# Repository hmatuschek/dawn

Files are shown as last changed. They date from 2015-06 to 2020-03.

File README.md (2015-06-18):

# Bluetooth controlled dawn simulator

This is a simple Bluetooth controlled bedside light which can act as a dawn simulator.

**Disclaimer**: The hardware schematics provided here deal with relatively high currents 
(depending on the LED used, >1A) which may even cause fire. If you rebuild the hardware,
you do that on our own risk! I am not responsible for any damage caused by the circuits 
or the software provided here. In general, do not rebuild the hardware if you do not 
understand the circuit completely!

## Hardware

The hardware ([schematics](https://github.com/hmatuschek/dawn/blob/master/doc/lampe_brd.pdf) 
can be found in the hardware/ directory) consists of a high-power LED, a current regulator
(BUZ11 + 2x BC547),  an ATMega168 MCU, a real-time clock (DS1307) with back-up battery
and a RS232 Bluetooth interface module (JY-MCU).

The [circuit](https://github.com/hmatuschek/dawn/blob/master/doc/lampe_brd.pdf) can be 
adopted easily to different LEDs by changing the value of R25 and/or R30 such that 
R25||R30 = 0.6/Imax, where Imax is the maximum current through the LED. Please be aware 
that the MOSFET Q4 as well as the LED may need some cooling.

The brightness of the LED will be controlled by the PWM output (pin 15) of the ATMega.

The firmware for the ATMega168 can be found in the firmware/ directory.

## Software

The software can be found in the src/ directory and provides a simple GUI using QT5 to configure and
control the dawn simulator. 

The dawn simulator is interfaced via Bluetooth, hence you must first connect to the device using the 
OS Bluetooth configuration. This will create a new serial port (RS232) which needs to be selected 
within the GUI application. 

## Communication protocol

The communication protocol is a trivial binary one. Every command/request is transmitted in terms of 
messages. The basic message structure is

    +--------+-- ... --+-- ... --+
    |  CMD   | PAYLOAD |   MAC   |
    +--------+---... --+-- ... --+

Each command message consists of a 8-bit command field, an optional Payload (variable size)
and a message authentication code (64 bit).

The RS232 Bluetooth module has only a 4-digit PIN for the access control. Hence some
additional measures are needed. Every message send to the device is therefore authenticated
using a simple MAC. The MAC is computed over the CMD and PAYLOAD fields of the message 
using the SIPHASH(2,4) function with a shared secret. This does not provide a very high 
level of security but may be considered sufficient for a bedside light.

Please note that the device will not send any response on an error. I.e. if an invalid command is received 
or if the MAC is invalid.

### (H)MAC algorithm

The signature (64bit) is simply the SipHash-2-4 of the message body with a shared 128bit secret.

  MAC = siphash24(MESSAGE, SECRET)

Please note that there is no IV that changes with every command. Hence the protocol is in principle 
vulnerable to replay attacks. Although the Bluetooth authentication is secured using a trivial 
4-digit PIN, the actual communication is encrypted with a relatively strong algorithm and key. 
Unless an attacker is able to capture the pairing, the communication should be relatively robust 
against trivial replay attacks. 

### GET_VALUE command (0x01)

Returns the current luminescence value of the lamp. This command has no payload.

The response contains the current value as a uint16_t as the payload.

### SET_VALUE command (0x02)

Sets the current luminescence value of the lamp.

The command payload contains the value as a uint16_t.

On success, a single byte (0x00) is returned.

### GET_TIME command (0x03)

Returns the current date and time of the RTC.

The command has no payload.

The response payload has the following structure

YEAR:MONTH:DAY:DAYOFWEEK:HOUR:MINTUE:SECOND

Where YEAR is transmitted as a uint16_t and MONTH, DAY, DAYOFWEEK, HOUR, MINUTE and SECOND as
uint8_t.

### SET_TIME command (0x04)

Set the current date and time of the RTC.

The command payload has the following structure

YEAR:MONTH:DAY:DAYOFWEEK:HOUR:MINTUE:SECOND

Where YEAR is transmitted as a uint16_t and MONTH, DAY, DAYOFWEEK, HOUR, MINUTE and SECOND as
uint8_t.

On success, a single byte (0x00) is returned.

### GET_ALARM command (0x05)

Returns the settings for the i-th alarm, where i in [0,6]

The payload contains the index of the alarm as a uint8_t.

The response Payload has the following format

DOW_FLAGS:HOUR:MINUTE

The first bit (MSB) is reserved (0), followed by 7 bits encoding the day of the week at which 
the alarm is enabled. 

0b0000001 - Sunday
0b0000010 - Monday
0b0000100 - Tuesday
0b0001000 - Wednesday
0b0010000 - Thursday
0b0100000 - Friday
0b1000000 - Saturday

Hence a value of 0x7f will enable the alarm on every day and a value of 0x00 will effectively disable
the alarm.

HOUR and MINUTE are encoded as uint8_t.

### SET_ALARM command (0x06)

Sets the i-th alarm settings, where i in [0,6].

The command payload has the following format:

IDX:DOW_FLAGS:HOUR:MINUTE

Where IDX is encodes the alarm index as uint8_t. The 7 least significant bits of DOW_FLAGS encode 
the day of the week at which the alarm is enabled.

0b0000001 - Sunday
0b0000010 - Monday
0b0000100 - Tuesday
0b0001000 - Wednesday
0b0010000 - Thursday
0b0100000 - Friday
0b1000000 - Saturday

HOUR and MINUTE are encoded as uint8_t.

### GET_TEMP command (0x07)

Returns the core and ambient temperature in K.

The response has the following format

CORE_TEMP:AMB_TEMP

where both variables are 16bit integer values (MSB first). Some MCUs do not
provide a core temperature sensor. In this case 0xffff is returned.

## License

dawn - A dawn-simulating bedside light.

Copyright (C) 2015  Hannes Matuschek

This program and harware is "free software"; you can redistribute it 
and/or modify it under the terms of the GNU General Public License
as published by the Free Software Foundation; either version 2 of 
the License, or (at your option) any later version.

This program and hardware is distributed in the hope that it will be useful,
but WITHOUT ANY WARRANTY; without even the implied warranty of
MERCHANTABILITY or FITNESS FOR A PARTICULAR PURPOSE.  See the
GNU General Public License for more details.

You should have received a copy of the GNU General Public License along
with this program; if not, write to the Free Software Foundation, Inc.,
51 Franklin Street, Fifth Floor, Boston, MA 02110-1301 USA.

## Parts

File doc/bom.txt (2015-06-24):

Qty Value           Device             Package         Parts    Description                          
1   10              R-EU_0204/7        0204/7          R24      RESISTOR
1   560             R-EU_0207/17       0207/17         R26      RESISTOR, European symbol            
2   1k              R-EU_0204/2V       0204V           R1, R28  RESISTOR
1   4.7k            R-EU_0207/10       0207/10         R27      RESISTOR, European symbol            
4   10k             R-EU_0204/2V       0204V           R13, R29, R12, R11 RESISTOR
1   1W              R-EU_0411/12       0411/12         R25      RESISTOR
1   10k             B57164             B57164          R2       SIEMENS NTC                          

2   22pF            C-EU025-025X050    C025-025X050    C7,C6    CAPACITOR
2   100nF           C-EU025-025X050    C025-025X050    C8, C9   CAPACITOR, European symbol           
1   100pF           C-EU025-025X050    C025-025X050    C10      CAPACITOR, European symbol           
1   100uF/35V       CPOL-EUE5-6        E5-6            C1       POLARIZED CAPACITOR

1   100uH           L-EU6000-XXX-RC    6000-XXXX-RC    L1       INDUCTOR, European symbol            

1   32.768kHz       CRYSTALTC26V       TC26V           Q3       CRYSTAL                              
1   16Mhz           CRYSTALHC18U-V     HC18U-V         Q2       CRYSTAL                              

1   ATMEGA328-20P   ATMEGA328-20P      DIL28-3         IC1      MICROCONTROLLER                      
1   JY-MCU          JY-MCU             JY-MCU          U$1      BLUETOOTH MODULE                                     

1   SB140           ZENER-DIODEDO35Z10 DO35Z10         D1       Z-Diode                              
2   BC547B          -NPN-TO92-EBC      TO92-EBC        T3, T4   NPN Transistror                      
1   BUZ11BV         BUZ11BV            TO220BV         Q4       N-CHANNEL MOS FET                    
1   DS1307          DS1307             DIL08           IC3      DS1307                               

2   MKDSN1,5/2-5,08 MKDSN1,5/2-5,08    MKDSN1,5/2-5,08 X1, X2   MKDSN 1,5/ 2-5,08 Printklemme        
1   PF750           PF750              PF752           KK1      HEATSINK                             
1   SL-340/P        SL-340/P           BEL/P           G1       LI BATTERY Sonnenschein

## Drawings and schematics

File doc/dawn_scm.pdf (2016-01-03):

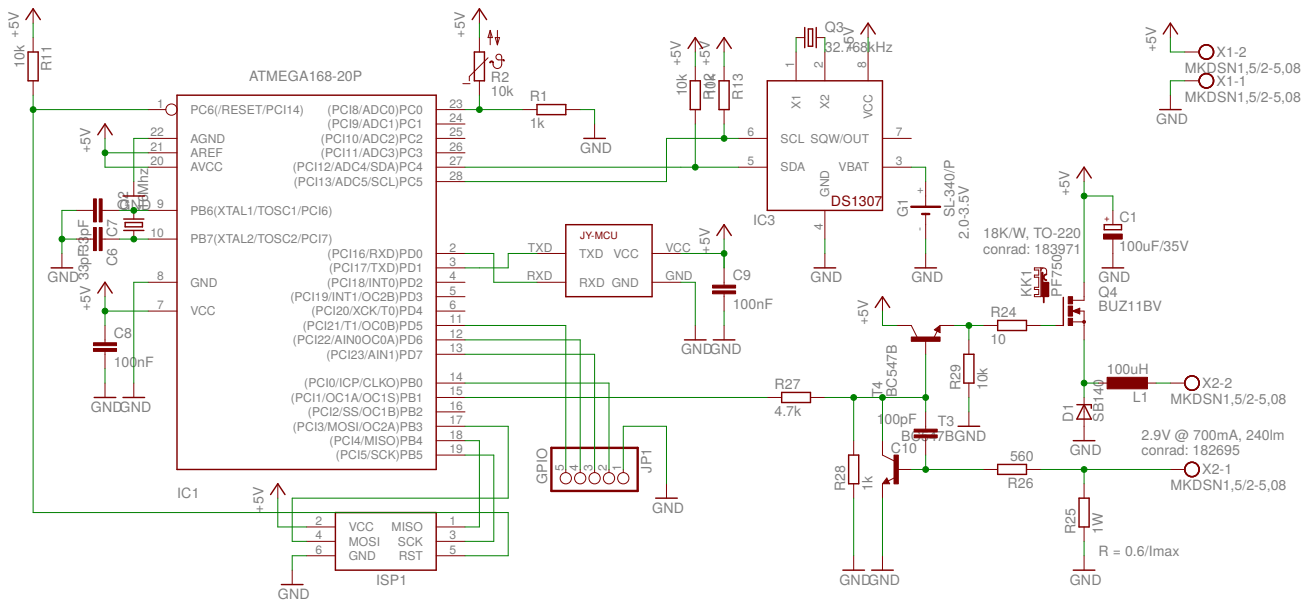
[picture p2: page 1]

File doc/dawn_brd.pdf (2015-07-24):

68.58

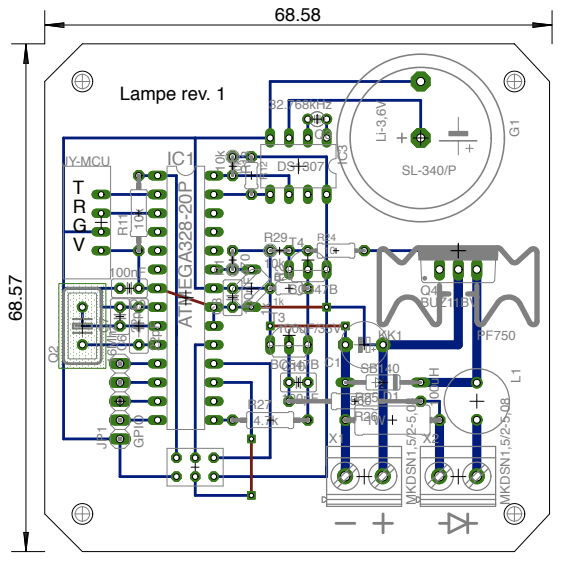
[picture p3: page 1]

JY-MCU
T R V

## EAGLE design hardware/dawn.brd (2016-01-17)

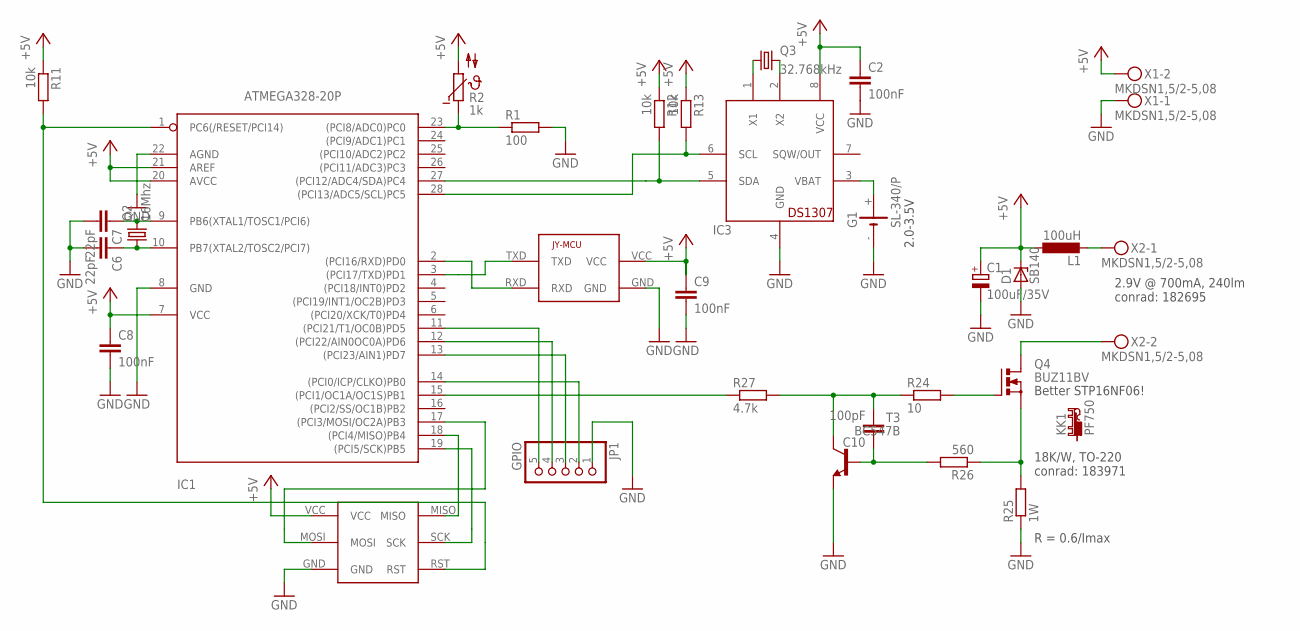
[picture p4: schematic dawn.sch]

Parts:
C1: 100uF/35V; E5-6
C2, C8, C9: 100nF; C025-025X050
C6: 22pF; C050-025X075
C7: 22pF; C025-025X050
C10: 100pF; C025-025X050
D1: SB140; DO35Z10
G1: SL-340/P; BEL/P
IC1: ATMEGA328-20P; DIL28-3
IC3: DS1307; DIL08
JP1: GPIO; 1X05
KK1: PF750; PF752
L1: 100uH; 6000-XXXX-RC
Q2: 16Mhz; HC18U-V
Q3: 32.768kHz; TC26V
Q4: BUZ11BV; TO220BV
R1: 100; 0204V
R2: 1k; B57164
R11: 10k; 0207/10
R12: 10k; 0204/5
R13: 10k; 0204V
R24: 10; 0204/7
R25: 1W; 0411/12
R26: 560; 0207/17
R27: 4.7k; 0207/10
T3: BC547B; TO92-EBC
U$1: JY-MCU
U$2: AVR-ISP
X1, X2: MKDSN1,5/2-5,08

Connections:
+5V: C1.+, C2.1, C8.1, C9.1, D1.C, IC1.7 (VCC), IC1.20 (AVCC), IC1.21 (AREF), IC3.8 (VCC), L1.1, R2.2, R11.1, R12.1, R13.1, U$1.VCC, U$2.VCC, X1.2
GND: C1.-, C2.2, C6.2, C7.2, C8.2, C9.2, D1.A, G1.-, IC1.8 (GND), IC1.22 (AGND), IC3.4 (GND), JP1.1, R1.2, R25.1, T3.E, U$1.GND, U$2.GND, X1.1
unnamed: IC1.15 ((PCI1/OC1A/OC1S)PB1), R27.1
unnamed: IC1.18 ((PCI4/MISO)PB4), U$2.MISO
unnamed: IC1.19 ((PCI5/SCK)PB5), U$2.SCK
unnamed: IC1.1 (PC6(/RESET/PCI14)), R11.2, U$2.RST
unnamed: IC1.17 ((PCI3/MOSI/OC2A)PB3), U$2.MOSI
unnamed: IC1.12 ((PCI22/AIN0OC0A)PD6), JP1.4
unnamed: IC1.11 ((PCI21/T1/OC0B)PD5), JP1.5
unnamed: IC1.13 ((PCI23/AIN1)PD7), JP1.3
unnamed: IC1.14 ((PCI0/ICP/CLKO)PB0), JP1.2
unnamed: IC1.23 ((PCI8/ADC0)PC0), R1.1, R2.1
unnamed: L1.2, X2.1
unnamed: C7.1, IC1.9 (PB6(XTAL1/TOSC1/PCI6)), Q2.2
unnamed: IC3.2 (X2), Q3.2
unnamed: IC3.1 (X1), Q3.1
unnamed: Q4.D, X2.2
unnamed: C6.1, IC1.10 (PB7(XTAL2/TOSC2/PCI7)), Q2.1
unnamed: IC1.28 ((PCI13/ADC5/SCL)PC5), IC3.6 (SCL), R13.2
unnamed: IC1.27 ((PCI12/ADC4/SDA)PC4), IC3.5 (SDA), R12.2
unnamed: G1.+, IC3.3 (VBAT)
unnamed: IC1.3 ((PCI17/TXD)PD1), U$1.TXD
unnamed: IC1.2 ((PCI16/RXD)PD0), U$1.RXD
unnamed: Q4.G, R24.2
unnamed: Q4.S, R25.2, R26.1
unnamed: C10.1, R26.2, T3.B
unnamed: C10.2, R24.1, R27.2, T3.C

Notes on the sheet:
2.9V @ 700mA, 240lm conrad: 182695
18K/W, TO-220 conrad: 183971
2.0-3.5V
R = 0.6/Imax
Better STP16NF06!

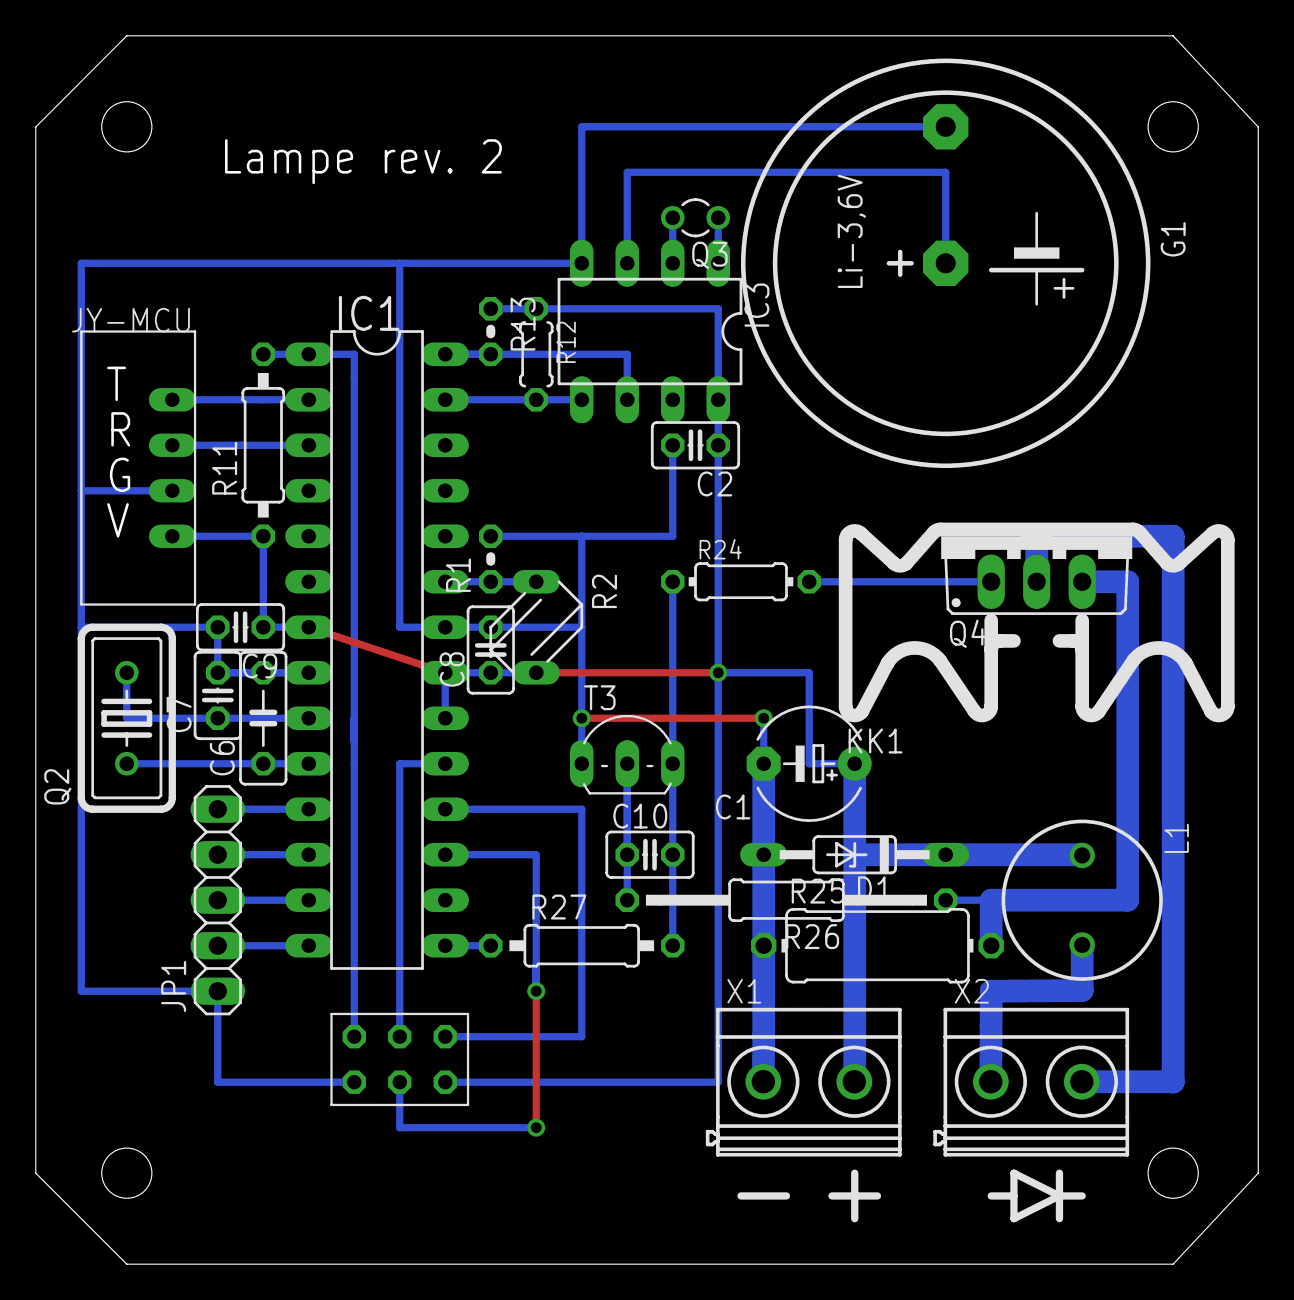
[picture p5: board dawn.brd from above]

Board: 2 copper layers, 68.2 x 68.6 mm, 31 parts (0 on the bottom side), 27 nets.

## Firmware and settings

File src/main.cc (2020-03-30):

#include <QApplication>
#include <QSerialPort>
#include <QMessageBox>
#include <QDateTime>
#include <QTranslator>
#include <QSettings>

#include "portdialog.hh"
#include "dawn.hh"
#include "mainwindow.hh"
#include "logger.hh"

#include <iostream>
#include <time.h>


int main(int argc, char *argv[])
{
  QApplication app(argc, argv);
  app.setApplicationName("dawn");
  app.setOrganizationDomain("hmatuschek.github.io");

  QTranslator translator;
  translator.load("://i18n/dawn.qm");
  app.installTranslator(&translator);

  QSettings settings("hmatuschek.github.io", "dawn");

  Logger::get().addHandler(new StreamLogHandler(LOG_DEBUG, std::cerr));

  Dawn *dawn = nullptr;
  QString name, systemLocation;
  QByteArray secret;

  // Let the user select an interfact to the device:
  while (true) {
    DeviceDialog dialog(settings);
    if (QDialog::Accepted != dialog.exec()) { return 0; }

    name = dialog.name();
    systemLocation = dialog.systemLocation();
    secret = dialog.secret();
    if (16 != secret.size()) { secret.resize(16); }

    QSerialPort *port = new QSerialPort(systemLocation);

    // Open port
    port->open(QIODevice::ReadWrite);
    if (! port->isOpen()) {
      LogMessage msg(LOG_ERROR);
      msg << "IO Error: Can not open device " << systemLocation.toStdString();
      Logger::get().log(msg);
      goto error;
    }
    if (! port->setBaudRate(QSerialPort::Baud38400)) {
      LogMessage msg(LOG_ERROR);
      msg << "IO: Can not set baudrate.";
      Logger::get().log(msg);
      goto error;
    }
    if (! port->setDataBits(QSerialPort::Data8)) {
      LogMessage msg(LOG_ERROR);
      msg << "IO: Can not set data bits.";
      Logger::get().log(msg);
      goto error;
    }
    if (! port->setParity(QSerialPort::NoParity)) {
      LogMessage msg(LOG_ERROR);
      msg << "IO: Can not set parity.";
      Logger::get().log(msg);
      goto error;
    }
    if (! port->setStopBits(QSerialPort::OneStop)) {
      LogMessage msg(LOG_ERROR);
      msg << "IO: Can not set stop bits.";
      Logger::get().log(msg);
      goto error;
    }
    if (! port->setFlowControl(QSerialPort::HardwareControl)) {
      LogMessage msg(LOG_ERROR);
      msg << "IO: Can not set stop bits.";
      Logger::get().log(msg);
      goto error;
    }
    if (! port->setDataTerminalReady(true)) {
      LogMessage msg(LOG_ERROR);
      msg << "IO: Can not set DTR.";
      Logger::get().log(msg);
      goto error;
    }

    dawn = new Dawn(port, (const uint8_t *)secret.constData());

    break;

error:
      QMessageBox::critical(
            0, QObject::tr("Can not access device."),
            QObject::tr("Can not access device at interface %1 (%2).").arg(
              name, systemLocation));
      if (dawn)
        delete dawn;
      else
        delete port;
      dawn = nullptr;
  }

  // Create main window
  MainWindow window(*dawn);
  window.show();

  // go...
  app.exec();

  return 0;
}

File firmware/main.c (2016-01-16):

#include <avr/io.h>
#include <avr/interrupt.h>
#include "communication.h"
#include "clock.h"
#include "temp.h"
#include "pwm.h"
#include "uart.h"

#include "i2c.h"
#include "ds1307.h"

int main(void)
{
  // Initialize UART interface
  comm_init();
  // Init all
  clock_init();
  // Init ADC
  temp_init();

  // Enable interrupts
  sei();

  // Wait for commands
  Command cmd;
  while (1) {
    if (! comm_wait(&cmd)) {
      comm_send_err();
      continue;
    }

    // Dispatch by command
    switch (cmd.command)
    {
      case GET_VALUE:
        comm_send_value(clock_get_value());
        break;

      case SET_VALUE:
        clock_set_value(cmd.payload.value);
        comm_send_ok();
        break;

      case GET_TIME:
        clock_get_datetime(&cmd.payload.datetime);
        comm_send_time(&cmd.payload.datetime);
        break;

      case SET_TIME:
        if (clock_set_datetime(&cmd.payload.datetime) ) {
          comm_send_ok();
        } else {
          comm_send_err();
        }
        break;

      case GET_ALARM:
        clock_get_alarm(cmd.payload.alarmIdx, &cmd.payload.alarm.alarm);
        comm_send_alarm(&cmd.payload.alarm.alarm);
        break;

      case SET_ALARM:
        if(clock_set_alarm(cmd.payload.alarm.alarmIdx, &cmd.payload.alarm.alarm)) {
          comm_send_ok();
        } else {
          comm_send_err();
        }
        break;

      case GET_TEMP:
        comm_send_temp(temp_get_core(), temp_get_external());
        break;

      case GET_NALARM:
        comm_send_nalarm(CLOCK_N_ALARM);
        break;

      case GET_NONCE:
        comm_send_nonce();
        break;

      default:
        comm_send_err();
        break;
    }
  }

  return 0;
}

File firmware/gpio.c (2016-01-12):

#include "gpio.h"
#include <avr/io.h>

// PIN0 -> PB0
// PIN1 -> PD7
// PIN2 -> PD6
// PIN3 -> PD5

#define KEY_HOLD_DUR  100

typedef struct {
  KeyState last_state;
  KeyState state;
  uint16_t tick_count;
} KeyContext;

static KeyContext keys[3] = {
  {KEY_NONE, KEY_NONE, 0},
  {KEY_NONE, KEY_NONE, 0},
  {KEY_NONE, KEY_NONE, 0}
};

void
key_init() {
  // PD7, PD6, PD5 are inputs
  DDRD  &= ~((1 << DDD7) | (1 << DDD6) | (1 << DDD5));
  // Enables pull-ups
  PORTD |= ((1 << DDD7) | (1 << DDD6) | (1 << DDD5));
  // Init keys
  keys[0].last_state = keys[0].state = KEY_NONE;  keys[0].tick_count = 0;
  keys[1].last_state = keys[1].state = KEY_NONE;  keys[1].tick_count = 0;
  keys[2].last_state = keys[2].state = KEY_NONE;  keys[2].tick_count = 0;
}


void key_update(uint8_t key) {
  // Get current output values:
  uint8_t k   = 1;
  switch (key) {
  case 0: k = (PIND & (1<<DDD7)); break;
  case 1: k = (PIND & (1<<DDD6)); break;
  case 2: k = (PIND & (1<<DDD5)); break;
  }
  if (0 == k) {
    switch (keys[key].last_state) {
    case KEY_NONE:
      keys[key].last_state = KEY_CLICK;
      keys[key].tick_count = 0;
      break;
    case KEY_CLICK:
      if (keys[key].tick_count == 5) {
        keys[key].last_state = KEY_HOLD;
        keys[key].state      = KEY_HOLD;
      } else {
        keys[key].tick_count++;
      }
      break;
    case KEY_HOLD:
      break;
    }
  } else {
    switch (keys[key].last_state) {
    case KEY_NONE:
      keys[key].state = KEY_NONE;
      break;
    case KEY_CLICK:
      keys[key].last_state = KEY_NONE;
      keys[key].state      = KEY_CLICK;
      break;
    case KEY_HOLD:
      keys[key].last_state = KEY_NONE;
      keys[key].state      = KEY_NONE;
      break;
    }
    keys[key].tick_count = 0;
  }
}


KeyState key(uint8_t key) {
  return keys[key].state;
}

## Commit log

2014-11-22 Initial import.
    [lampe.brd, lampe.sch]
2014-11-23 Fixed schematic & board.
    [dawn.brd, dawn.sch]
2015-06-17 Fixed current reg.
    [lampe.brd, lampe.sch]
2015-06-17 Updated circuit and board PDFs.
    [lampe.brd, lampe.sch]
2015-06-18 Fixed build scripts for compilation under linux.
    [clock.c]
2015-06-18 Updated schematics and firmware for ATMEGA328P.
    [dawn.brd, dawn.sch]
2015-07-27 Fixed touch sensor code.
    [gpio.c]
2015-07-27 Fixed stupid error in keygen.
    [communication.c]
2016-01-03 Fixed minors.
    [dawn.brd, dawn.sch]
2017-01-16 Fixed UART interface.
